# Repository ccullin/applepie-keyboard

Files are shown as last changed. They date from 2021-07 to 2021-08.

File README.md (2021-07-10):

# applepie keyboard
keyboard split and partially built
applepie is a 66 key split mechancial keyboard with RGB, OLED display and Bluetooth.  

## Respository contents:
- /**documentation** - build and config notes
- /**pcb** - EasyEDA files, Bill of Materials, Pick & Place, Gerber diles
- /**case** - STL files for 3D print

## Firmware:
[QMK fork](https://github.com/ccullin/qmk_firmware)

applepie keyboard will be added to the [QMK]https://github.com/qmk/qmk_firmware when once the following 2 pull requests are added.
- [PR#13480](https://github.com/qmk/qmk_firmware/pull/13480)
- [PR#13457](https://github.com/qmk/qmk_firmware/pull/13457)

## Product Versions:
There are 3 hardware configs, all using the same PCB.
1. **applepie** - base model [requires custom case that excludes OLED display cutout]
2. **applepie-rgb** - include RGB leds for each key and an OLED display
3. **appliepie-ble** - includes RGB, OLED and Bluetooth Low Energy with a 4000mAh battery.

## Supported Features:
the be added soon

## Layout:
66 key layout

## License information:

This project is licensed under the Creative Commons Attribution-NonCommercial 4.0 International License.

If you have remixed, adapted or build upon this work and wish to remove the non-commercial clause for your own project please contact me at chris@miplace.com. Your request is more than likely to be granted. The non-commercial part of the license is intended to avoid direct copies of the work to be sold for commercial gain by third parties.

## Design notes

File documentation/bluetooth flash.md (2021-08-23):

# Bluetooth BLE module configuration

The bluetooth keyboard is based on the Nordic nRF51822 chip and is flashed with the adafruit DFU bluetooth image.  The base module is available from multiple sources but must be flashed with adafruit code as QMK only supports this BLE firmware.

[nRF51822 module](https://www.adafruit.com/product/4076)

## Flashing procedure

### hardware setup
Flashing the nRF51822 module requires a progammer and the adafruit firmware image.

[useful hardware programming setup.](https://bitknitting.wordpress.com/category/ladybug-blue/)
[the hardware programmer I use.](https://www.nordicsemi.com/Products/Development-hardware/nrf51-dk).  There are cheaper options but I was not sure whether I would need to development my own firmware or not, so I went with the native Nordic developer kit.

### toolchain setup
In hindsight this is overkill.  I was preparing to develop the firmware but it turned out to be much easier.

Set up nr51DK SDK 
Setup tool chain per nordicsemi website

Latest version that supports nrf51 series of SOC is v10.0.  Documentation:
https://infocenter.nordicsemi.com/topic/com.nordic.infocenter.sdk51.v10.0.0/index.html
https://infocenter.nordicsemi.com/topic/com.nordic.infocenter.sdk51.v10.0.0/nrf51_getting_started.html

To build nrf51 examples
Update makefile.posix to point to where gcc is installed.  Refer doco above
Go to directory and run Make.

The only comamnd we'll use is nrfprog.

### flashing steps
download [adafruit BLE firmware images](https://github.com/adafruit/Adafruit_BluefruitLE_Firmware)  and save to your local drive.

	1. Bootloader:  `nrfjprog --program /Users/Development/Downloads/Adafruit_BluefruitLE_Firmware-master/bootloader/bootloader_0002.hex -f nrf51 --chiperase`
*Located in the Github files downloaded from Adafruit. for me this is /Users/Development/Downloads/Adafruit_BluefruitLE_Firmware-master/bootloader*
		
	2. S110 soft device:  `nrfjprog --program  /Users/Development/Downloads/Adafruit_BluefruitLE_Firmware-master/softdevice/s110_nrf51_8.0.0_softdevice.hex -f nrf51`
*Located in /Users/Development/Downloads/Adafruit_BluefruitLE_Firmware-master/softdevice/s110_nrf51_8.0.0_softdevice.hex*
		
    3. BLE application: `nrfjprog --program /Users/Development/Downloads/Adafruit_BluefruitLE_Firmware-master/0.7.0/blefriend32/blefriend32_s110_xxac_0_7_0_160628_blefriend32.hex -f nrf51 --sectorerase`

The nRF51822 module can now be soldered to the main keyboard PCB.

*note PCB is designed to allow the nRF51822 module to be program onboard through the JTAG interface, but this requiers another hardware revision.*

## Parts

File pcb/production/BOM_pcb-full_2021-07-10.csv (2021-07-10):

ID | Name | Designator | Footprint | Quantity | Manufacturer Part | Manufacturer | Supplier | Supplier Part | Price
1 | OLED | CN6 | CONN-SMD_S4B-PH-SM4-TB(LF)(SN) | 1
2 | ISP | H1,H2 | HDR-3X2/2.54 | 2
3 | future | CN3 | HDR-TH_4P-P2.54-V | 1
4 | JTAG | H3 | HDR-TH_4P-P2.54-V | 1
5 | TEST | H4 | HDR-TH_4P-P2.54-V | 1
6 | MCP73831T-2ATI/OT | U7 | 7831_HEATSINK | 1
7 | IS31FL3737 | U6 | QFN-40 (5X5) | 1
8 | KEYBOARD | CN1,CN4 | AUDIO-TH_PJ-3200B-4A | 2
9 | Batt | CN7 | CONN-SMD_P2.00_S2B-PH-SM4-TB(LF)(SN) | 1
10 | BAT_ON | SW69 | SW-SMD_K3-1296S-J1 | 1
11 | RST | SW68,SW31 | SW-SMD_4P-L4.5-W4.5-P3.00-LS7.0 | 2
12 | PMEG2010AEH,115 | D31,D68 | SOD-123F_L2.8-W1.8-LS3.7-RD | 2
13 | BT_MODE | LED2 | LED0603-R-RD | 1
14 | CHRG | LED1 | LED0603-R-RD | 1
15 | BT_CONN | LED3 | LED0603-R-RD | 1
16 | 2K | R27 | R0603 | 1
17 | 2.2K | R19,R18,R29,R28 | R0603 | 4
18 | CHRGD | LED4 | LED0603-R-RD | 1
19 | MC-311D | USB-C2,USB-C1 | USB-C-SMD_MC-311D_LARGE | 2
20 | DMP2035U-7 | Q1 | SOT-23-3_L2.9-W1.6-P1.90-LS2.8-BR | 1
21 | 1A 6V | F2,F1 | F0805 | 2
22 | 5.1K | R23,R22,R9,R8 | R0603 | 4
23 | 1N4148W_C81598 | D49,D69,D32,D65,D55,D54,D46,D48,D40,D61,D59,D45,D53,D60,D44,D52,D67,D43,D51,D58,D42,D50,D62,D57,D41,D66,D56,D64,D47,D63,D39,D38,D37,D36,D35,D34,D33,D1,D2,D3,D4,D5,D6,D7,D8,D26,D14,D27,D21,D28,D15,D9,D22,D29,D16,D10,D23,D17,D11,D24,D18,D12,D25,D19,D13,D20,D30 | SOD-123_L2.8-W1.8-LS3.7-RD | 67
24 | 10uF | C17,C16,C1,C2 | C0603 | 4
25 | 8MHz | X2,X1 | OSC-SMD_L5.0-W3.2 | 2
26 | MDBT40 | MDBT1 | MDBT40 | 1
27 | 3.3V LDO | U4,U1 | SOT-25-5_L3.0-W1.8-P0.95-LS3.0-BR | 2
28 | 330 | R30,R16,R4 | R0603 | 3
29 | 150K | R33 | R0603 | 1
30 | 470nF | C28,C25,C29,C27,C10,C12,C13,C14 | C0603 | 8
31 | 10K | R17,R15,R3,R5 | R0603 | 4
32 | 1uF | C31,C19,C18,C3,C4 | C0603 | 5
33 | 20pF | C22,C21,C6,C7 | C0603 | 4
34 | 100nF | C24,C30,C26,C20,C5,C9,C11,C15 | C0603 | 8
35 | 20K | R24,R10 | R0603 | 2
36 | 22 | R21,R20,R6,R7 | R0603 | 4
37 | 180 | R31 | R0603 | 1
38 | 100K | R32,R25,R26,R14,R13,R1,R2,R12,R11 | R0603 | 9
39 | 22uF | C23,C8 | CAP-SMD_L2.0-W1.2-R-RD | 2
40 | ATMEGA32U4-AU | U5,U2 | VQFN-44_L7.0-W7.0-P0.50-BL-EP5.2 | 2
41 | IS31FL3737 | U3 | QFN-40 (5X5) | 1
42 | POGO | CN2,CN5 | 4_PIN_POGO_CONNECTOR | 2
43 | Cherry MX 2.75U | SW61,SW30 | CHERRY MX 2.25U | 2
44 | Cherry MX 2.25U | SW59,SW20 | CHERRY MX 2.25U | 2
45 | Cherry MX | SW33,SW34,SW35,SW36,SW37,SW38,SW39,SW63,SW47,SW64,SW56,SW66,SW49,SW41,SW57,SW50,SW42,SW58,SW51,SW43,SW67,SW52,SW44,SW60,SW53,SW45,SW62,SW40,SW48,SW46,SW54,SW55,SW65,SW32,SW1,SW2,SW3,SW4,SW5,SW6,SW7,SW8,SW9,SW10,SW11,SW12,SW13,SW14,SW15,SW16,SW17,SW18,SW19,SW21,SW22,SW23,SW24,SW25,SW26,SW27,SW28,SW29 | CHERRY MX RGB | 62

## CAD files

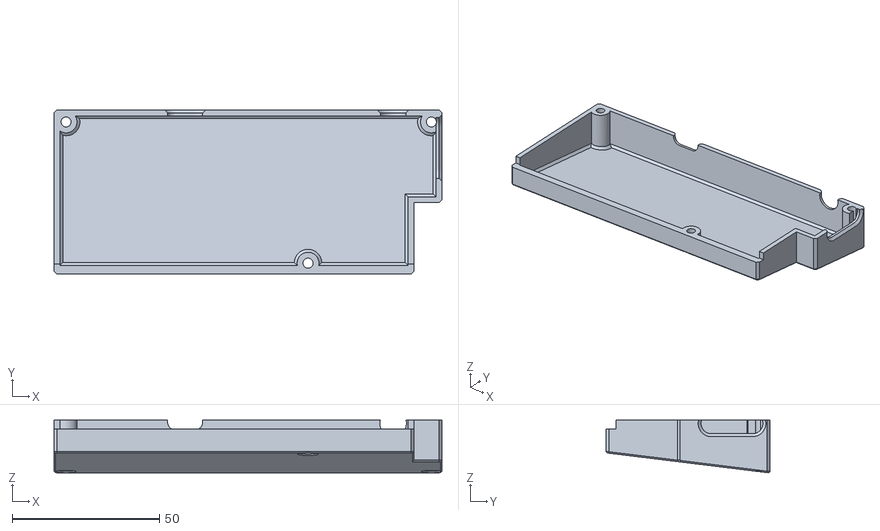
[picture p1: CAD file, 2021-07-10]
case/bottom left lid.stl
131.9 x 55.8 x 17.9

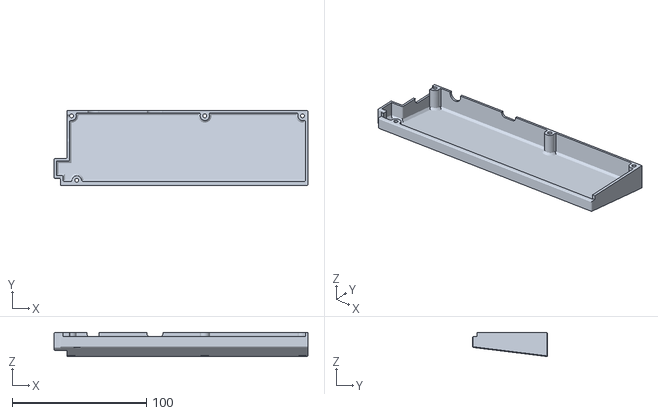
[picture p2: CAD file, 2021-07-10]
case/bottom right lid.stl
189.0 x 56.0 x 17.9

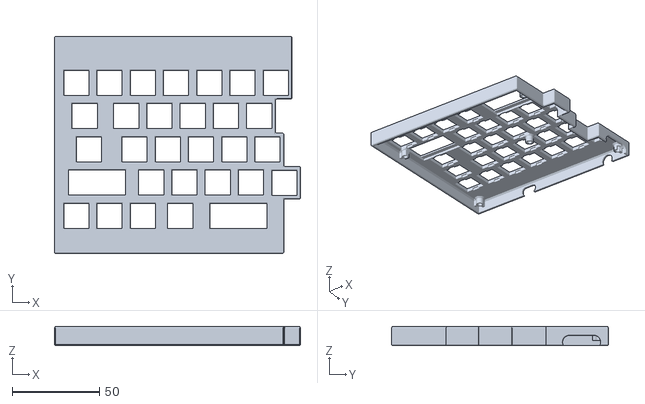
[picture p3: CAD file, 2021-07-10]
case/top left.stl
140.9 x 124.2 x 11.0

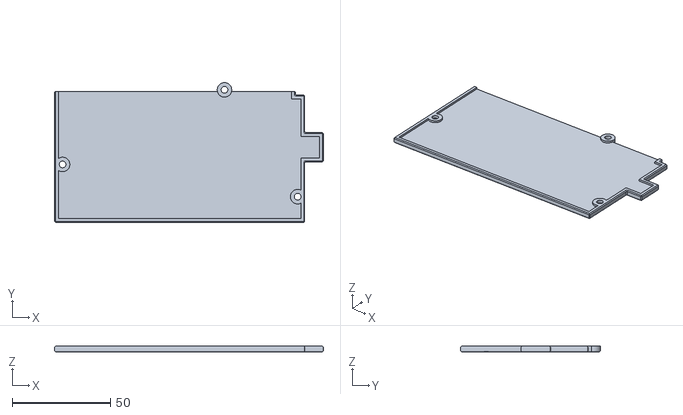
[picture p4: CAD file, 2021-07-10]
case/bottom left.stl
136.6 x 71.1 x 3.00

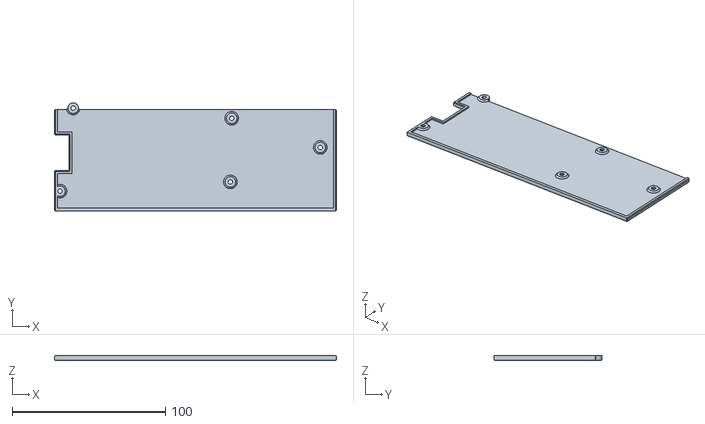
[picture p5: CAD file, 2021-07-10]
case/bottom right.stl
184.2 x 70.8 x 3.00

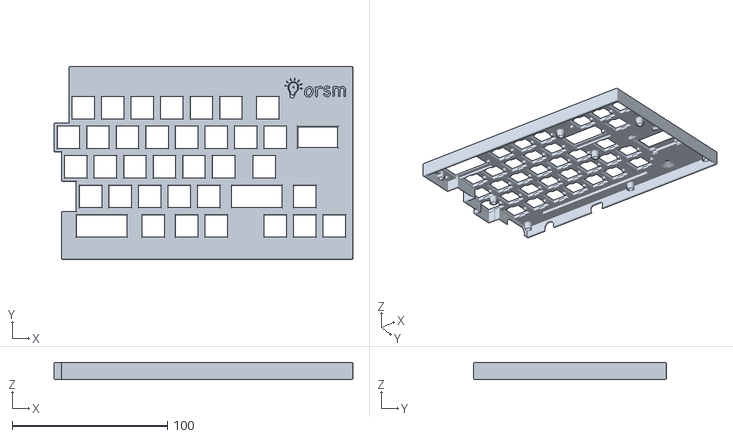
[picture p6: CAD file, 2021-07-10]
case/top right.stl
192.8 x 124.2 x 11.0

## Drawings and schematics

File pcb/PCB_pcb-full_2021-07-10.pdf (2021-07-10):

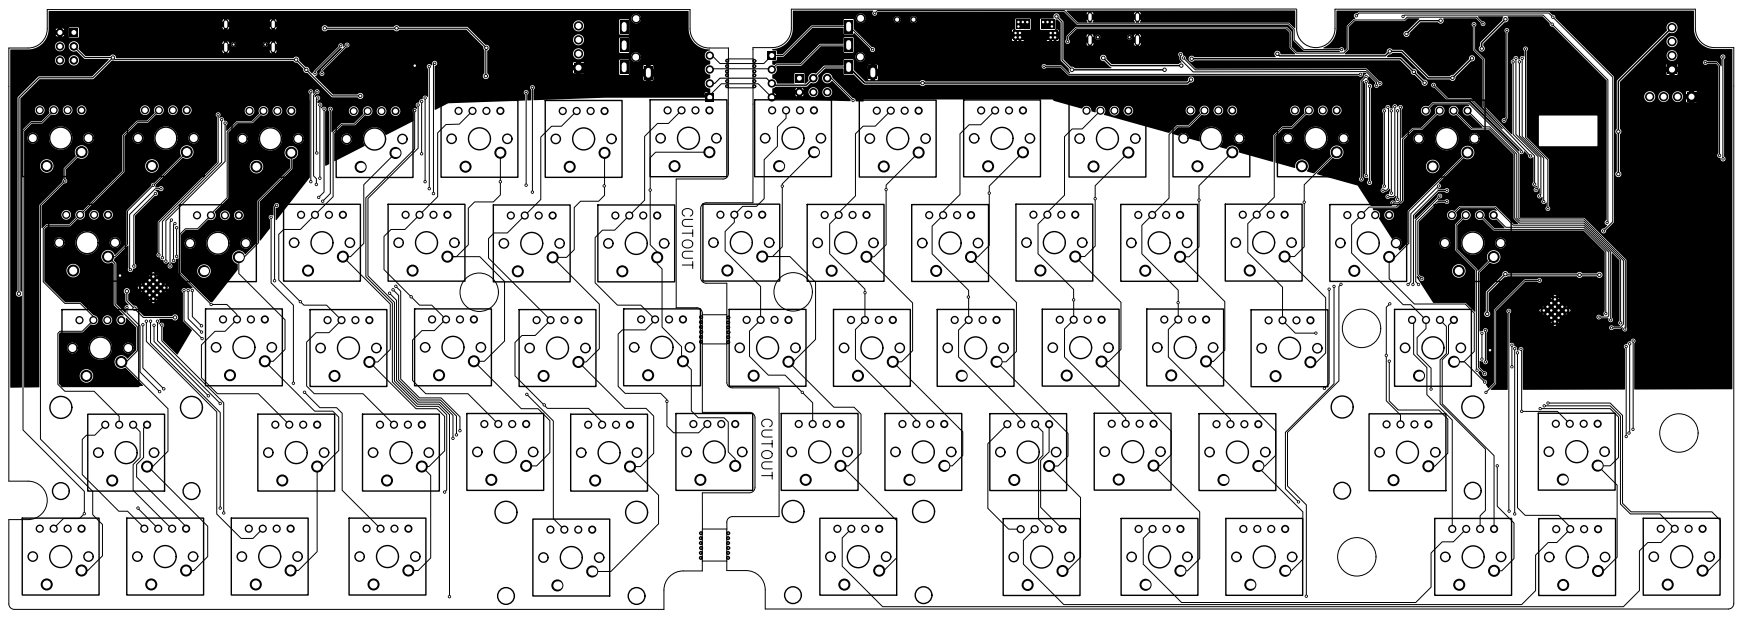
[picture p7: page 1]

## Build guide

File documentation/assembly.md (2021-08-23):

1. OLED.  ensure wires are soldered to the OLED display and clip into RHS top plate
2. PCB. 
    - install stablizers and trim overhole to PCB edges
    - insert on/off on switch over on RHS
    - insert pcb into top plate, feeding OLED cable for right half through PCB cutout
3. Keys.
    - click in ALL keys from top of top plate.  Ensure both pins of each key insert into PCB holes.
    - Solder ONE (1) pin for each corner key and centre key
    - heating the solder pin press the key and pcb **firmly** together to ensure full insertion
    - Repeat for all keys
    - visually inspect all keys are fully inserted
    - Solder second pin for each key
4. LEDs.
    - insert all RGB Leds, ensuring correct anode position
    - solder anode for each led
    - for each led, heat Anode solder joint and press LED **firmly** into position
    - vidually inspect each LED for full insertion
    - solder and trim all leads
5. Flash and test.
    - Flash keyboard halves and test.   *note to flash left with dfu-split-left and right with dfu-split-right ont he first flash*
6. enjoy.
